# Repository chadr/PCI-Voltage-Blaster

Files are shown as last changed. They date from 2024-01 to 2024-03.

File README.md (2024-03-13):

# PCI Voltage Blaster
 PCI +3.3V version of the Voltage Blaster project. This is meant to power PCI cards keyed for +5V slots that still require +3.3V. Like the "new" Chinese made ATI Rage XL PCI cards found all over eBay.

 This mini version is good for about 500mA. It's not meant for high-powered PCI devices.

 NOTE: Most +5V only PCI motherboards don't route the +3.3V pins between slots. You will have to add bodge wires on the back of your motherboard between the slot with the Voltage Blaster and the slot that needs +3.3V.

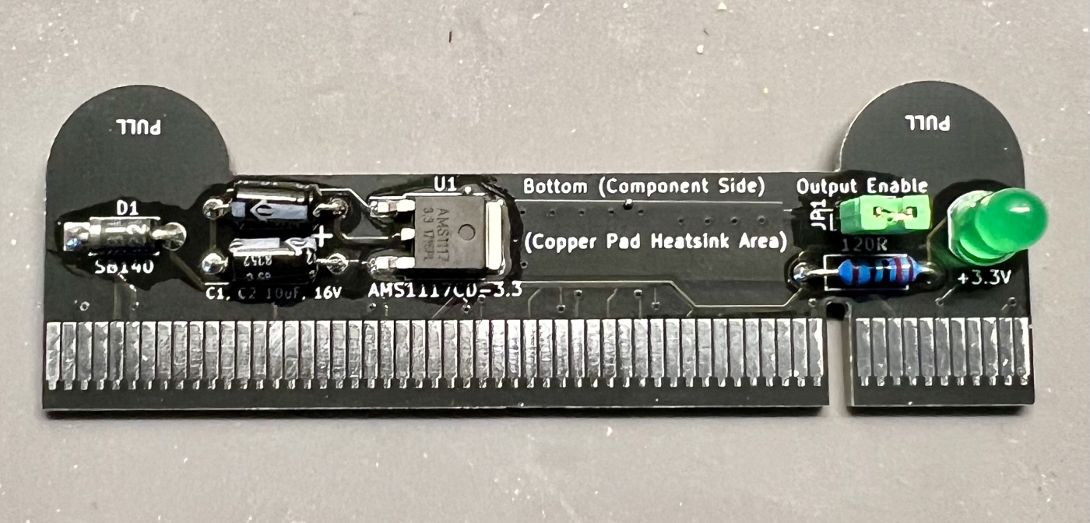
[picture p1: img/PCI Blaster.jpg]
Finished Voltage Blaster


## Getting Boards Made
Either JLCPCB or PCBWay do a decent job. Your choice for HASL or ENIG. Doesn't really matter here. Choose 1.6mm board thickness.

**Bill of Materials**
**Item**|**Qty**|**MFG Part Num**
:-----:|:-----:|:-----:
+3.3V LDO|1|AMS1117-3.3 (DPAK)
10uF 16V Axial Electrolytic Capacitor|2|Nichicon VX Series
5mm LED Diffused|1|Any Generic Red or Green 5mm LED
120R 1/8 Watt Metal Film Resistor 1%|1|Any
Schottky Diode 40 Volt 1.0 Amp|1|SB140-E3/73

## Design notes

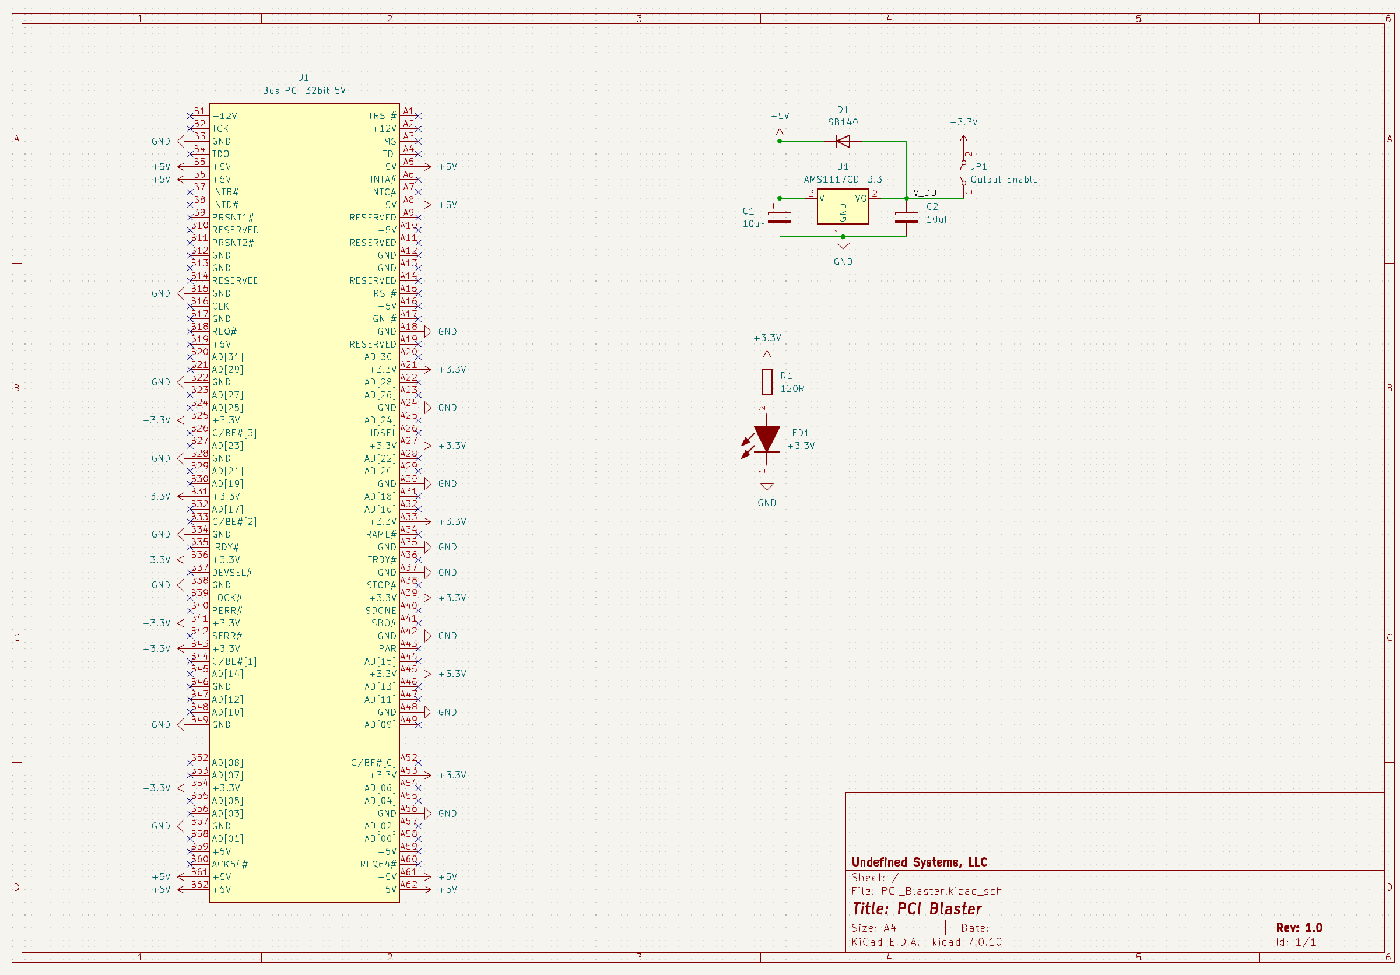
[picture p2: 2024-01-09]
img/PCI Blaster Schematic.png

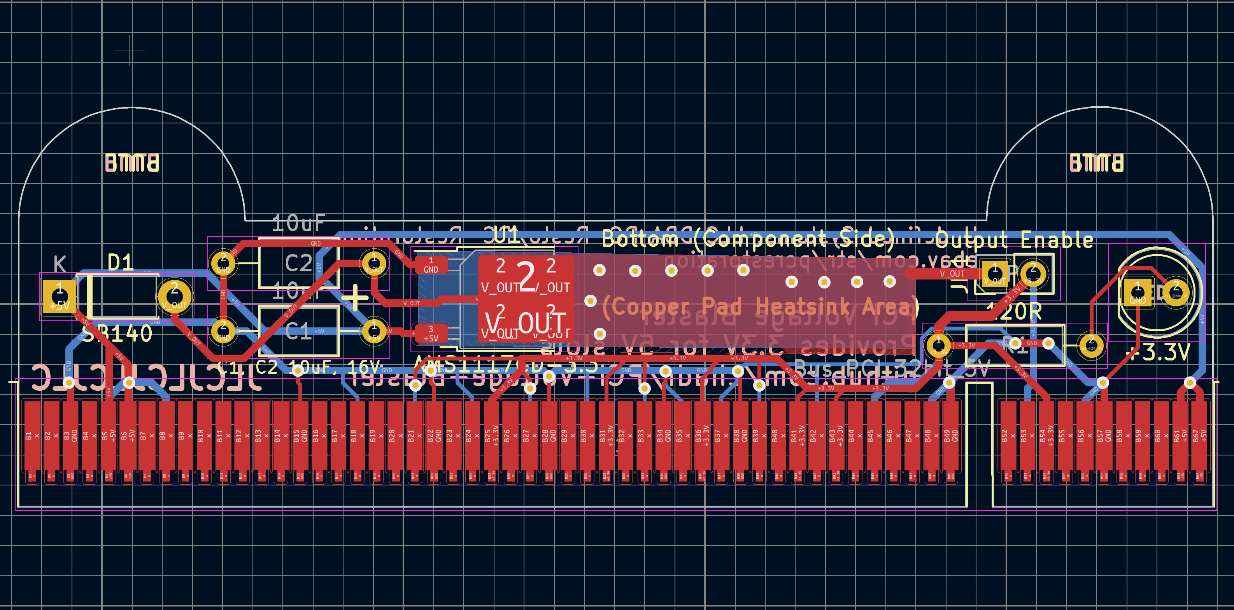
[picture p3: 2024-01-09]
img/PCI Blaster PCB.png

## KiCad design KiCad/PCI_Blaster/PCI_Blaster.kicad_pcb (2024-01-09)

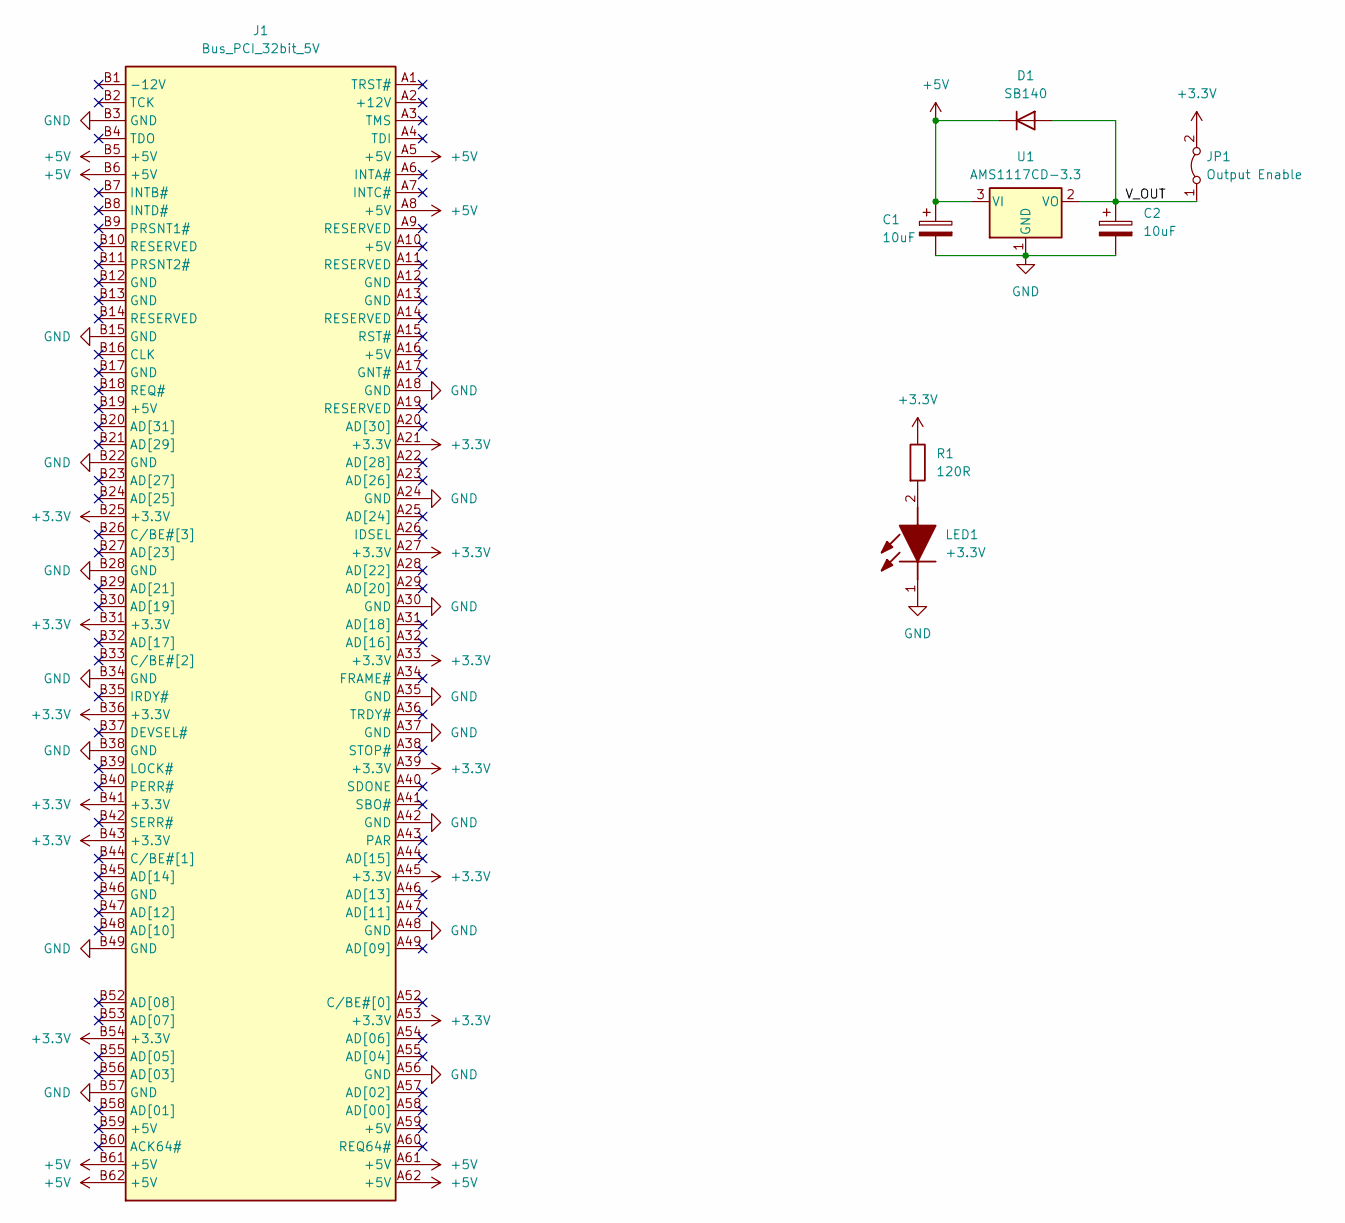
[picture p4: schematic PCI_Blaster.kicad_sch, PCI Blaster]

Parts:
C1, C2: 10uF; C_Axial_L5.1mm_D3.1mm_P10.00mm_Horizontal
D1: SB140; D_DO-41_SOD81_P7.62mm_Horizontal
J1: Bus_PCI_32bit_5V; BUS_PCI
JP1: Output Enable; PinHeader_1x02_P2.54mm_Vertical
LED1: +3.3V; LED_D3.0mm; Manufacturer_Part_Number LTL-4231NHBP; Mouser Part Number 859-LTL-4231NHBP
R1: 120R; R_Axial_DIN0204_L3.6mm_D1.6mm_P5.08mm_Horizontal
U1: AMS1117CD-3.3; TO-252-2

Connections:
+3.3V: J1.A21 (+3.3V), J1.A27 (+3.3V), J1.A33 (+3.3V), J1.A39 (+3.3V), J1.A45 (+3.3V), J1.A53 (+3.3V), J1.B25 (+3.3V), J1.B31 (+3.3V), J1.B36 (+3.3V), J1.B41 (+3.3V), J1.B43 (+3.3V), J1.B54 (+3.3V), JP1.2 (B), R1.1
+5V: C1.1, D1.1 (K), J1.A5 (+5V), J1.A8 (+5V), J1.A61 (+5V), J1.A62 (+5V), J1.B5 (+5V), J1.B6 (+5V), J1.B61 (+5V), J1.B62 (+5V), U1.3 (VI)
/V_OUT: C2.1, D1.2 (A), JP1.1 (A), U1.2 (VO)
GND: C1.2, C2.2, J1.A18 (GND), J1.A24 (GND), J1.A30 (GND), J1.A35 (GND), J1.A37 (GND), J1.A42 (GND), J1.A48 (GND), J1.A56 (GND), J1.B3 (GND), J1.B15 (GND), J1.B22 (GND), J1.B28 (GND), J1.B34 (GND), J1.B38 (GND), J1.B49 (GND), J1.B57 (GND), LED1.1 (K), U1.1 (GND)
unnamed: LED1.2 (A), R1.2

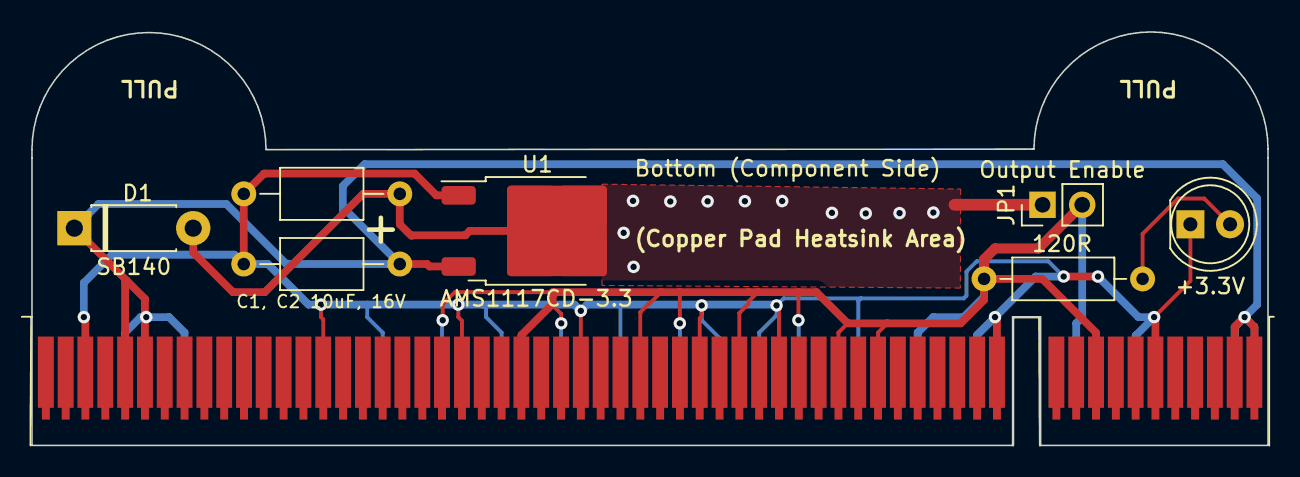
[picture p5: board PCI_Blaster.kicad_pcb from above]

Board: 2 copper layers, 79.2 x 26.5 mm, 8 parts (0 on the bottom side), 5 nets.

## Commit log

2023-11-03 add panels
    [PCI Blaster Mouse Bites-B_Cu.gbr, PCI Blaster Mouse Bites-B_Mask.gbr, PCI Blaster Mouse Bites-B_Paste.gbr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]
2024-01-09 redo pcb layout
    [PCI Blaster Mouse Bites-B_Cu.gbr, PCI Blaster Mouse Bites-B_Mask.gbr, PCI Blaster Mouse Bites-B_Paste.gbr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]
